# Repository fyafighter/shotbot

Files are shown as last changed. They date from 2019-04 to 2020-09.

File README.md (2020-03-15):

Shotbot is a Lacrosse goalie training system.

It runs on a raspberry pi and uses 3 docker containers: 
redis, api, and worker.

The default user on the raspberry pi is "pi" 
(naturally - however I write this down as I forgot it after not logging into the machine for 9 months after I set it up...)

1. Setup the raspberry pi.
https://www.raspberrypi.org/downloads/raspbian/

2. Install docker:
curl -fsSL get.docker.com -o get-docker.sh && sh get-docker.sh
sudo usermod -aG docker pi
newgrp docker

3. Install Docker Compose
sudo apt-get install libffi-dev libssl-dev
sudo apt-get install -y python python-pip
sudo apt-get remove python-configparser

Add vm.overcommit_memory = 1 to /etc/sysctl.conf

4. Checkout, build, and run
git clone https://github.com/fyafighter/shotbot.git
cd shotbot
docker-compose up --build

5. Download and install the app.
This can be done manually today by building and deploying from the flutter application. 
cd shotbot_app 
code .

TODO: Publish the app. 

DETAILS ON THE TARGETING SYSTEM
The Shotbot is setup on a 3x3 grid for targetting. The easiest way to get started is to start up the shotbot and the app, then center the system with the controls in the app, and then use the various shooting modes.

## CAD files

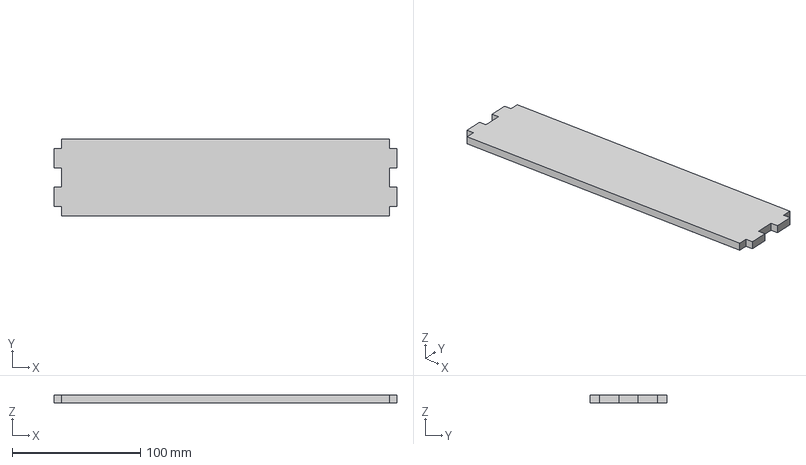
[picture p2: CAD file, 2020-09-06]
drawings/print-parts/tilt tray.step
267.0 x 60.0 x 6.00 mm

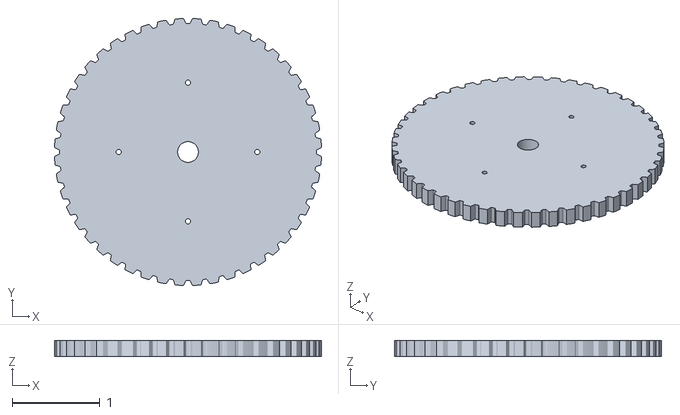
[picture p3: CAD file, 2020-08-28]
drawings/v2/tilt-XL-timing-pulley.stl
3.03 x 3.03 x 0.188

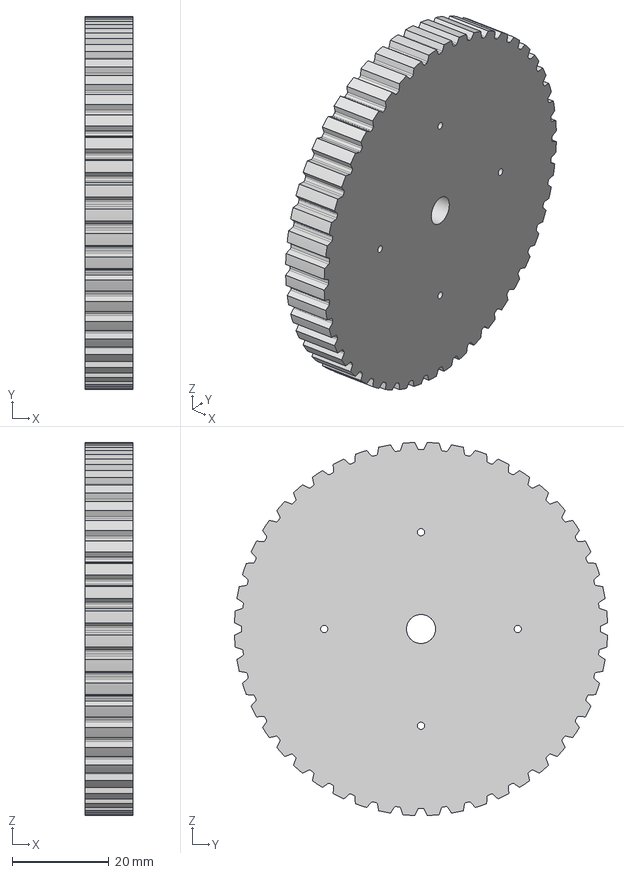
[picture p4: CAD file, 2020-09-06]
drawings/print-parts/Large gear.step
10.0 x 77.1 x 77.1 mm

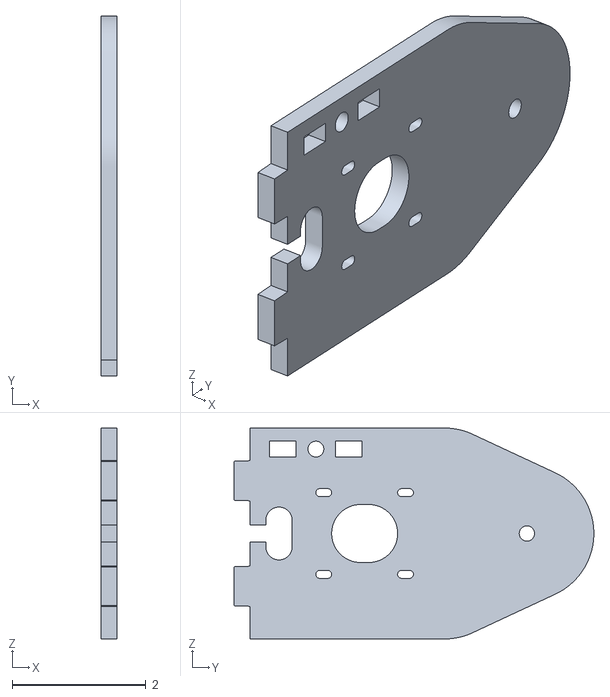
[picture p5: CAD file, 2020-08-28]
drawings/v2/pan-tray-flange.stl
0.236 x 5.37 x 3.15

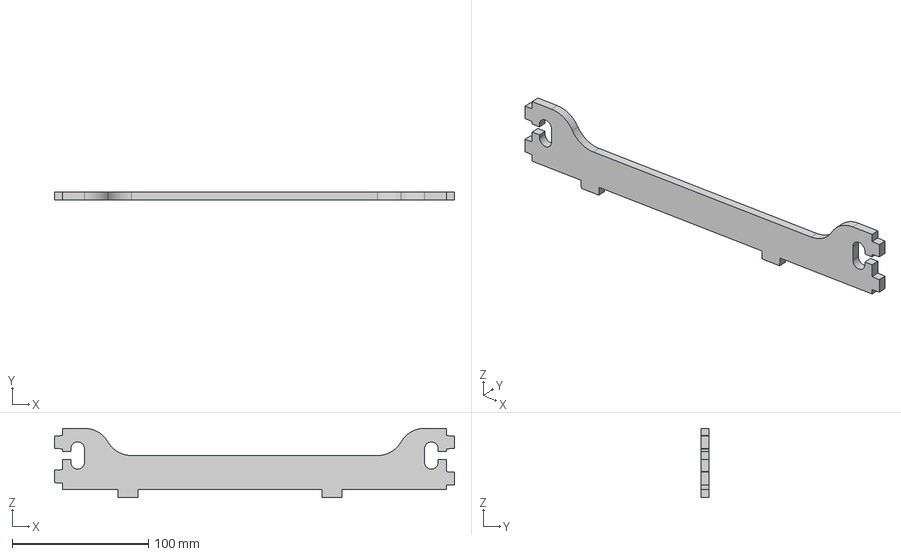
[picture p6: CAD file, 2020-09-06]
drawings/print-parts/Back support.step
294.0 x 6.00 x 51.0 mm

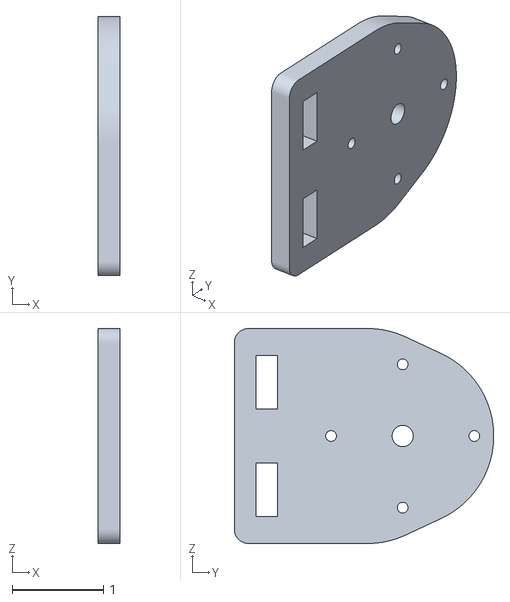
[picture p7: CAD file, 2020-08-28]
drawings/v2/tilt-tray-flange.stl
0.236 x 2.85 x 2.36

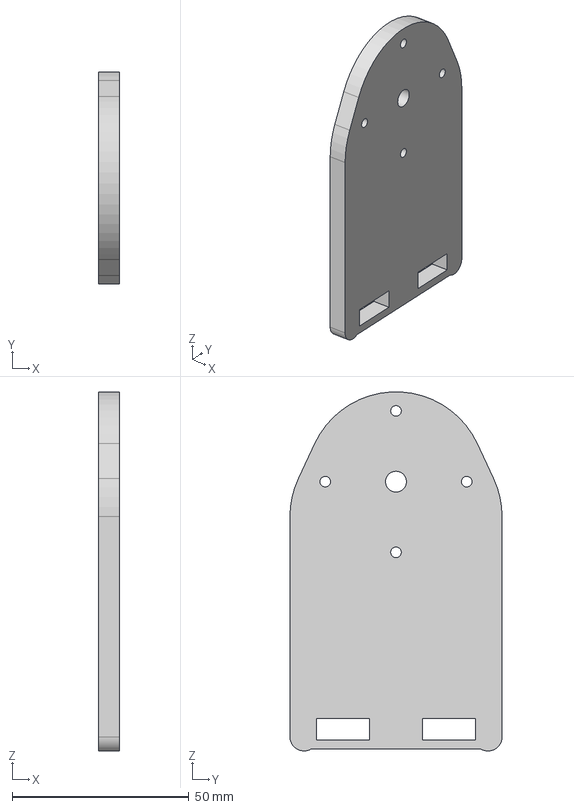
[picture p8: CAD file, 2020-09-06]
drawings/print-parts/Tilt Flange 2.step
6.00 x 60.0 x 101.5 mm

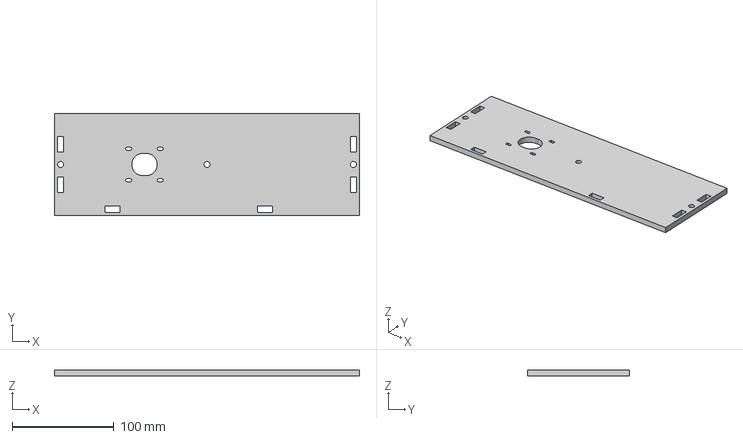
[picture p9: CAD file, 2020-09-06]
drawings/print-parts/Base Tray.step
300.0 x 100.0 x 6.00 mm

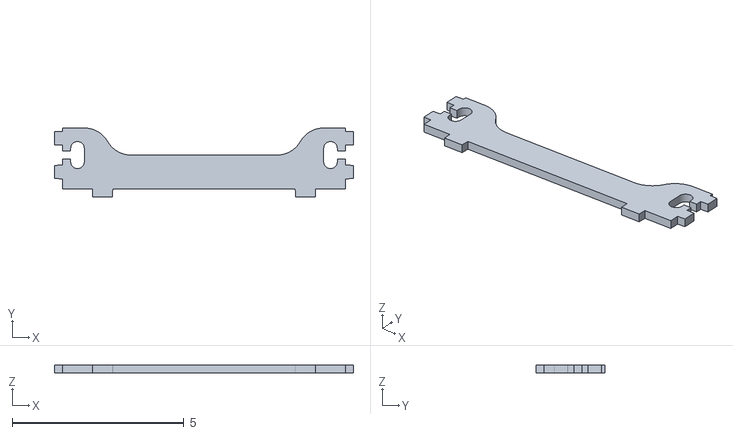
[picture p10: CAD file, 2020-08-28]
drawings/v2/pan-brace.stl
8.70 x 2.01 x 0.236

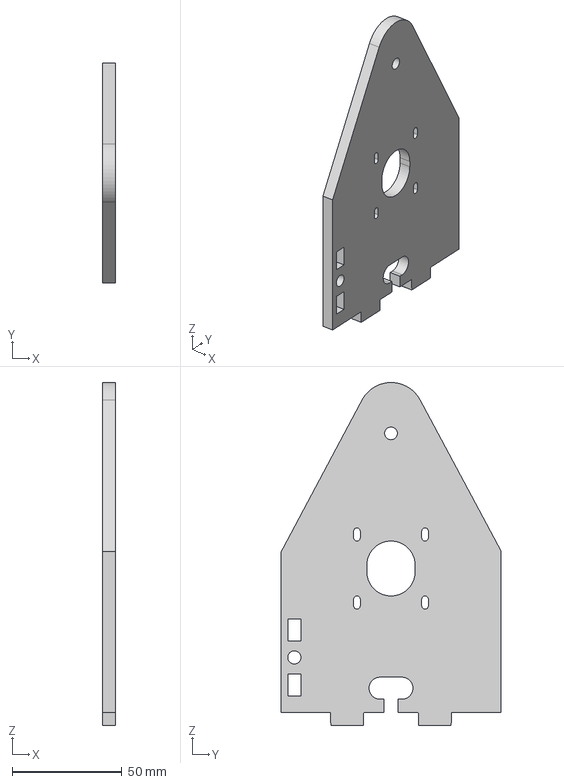
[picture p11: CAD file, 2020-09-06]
drawings/print-parts/Flange 2.step
6.00 x 100.0 x 156.2 mm

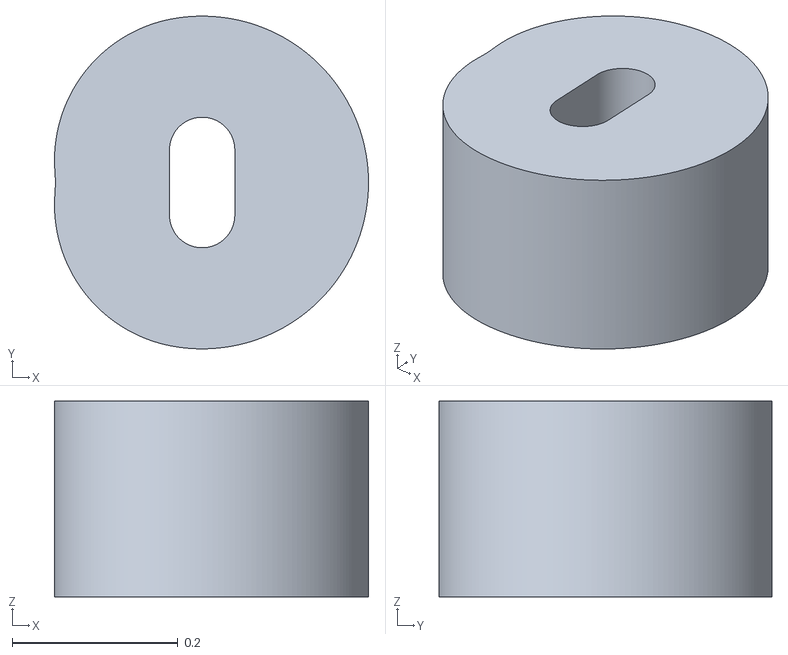
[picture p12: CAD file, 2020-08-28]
drawings/v2/drive-pulley-key.stl
0.379 x 0.402 x 0.236

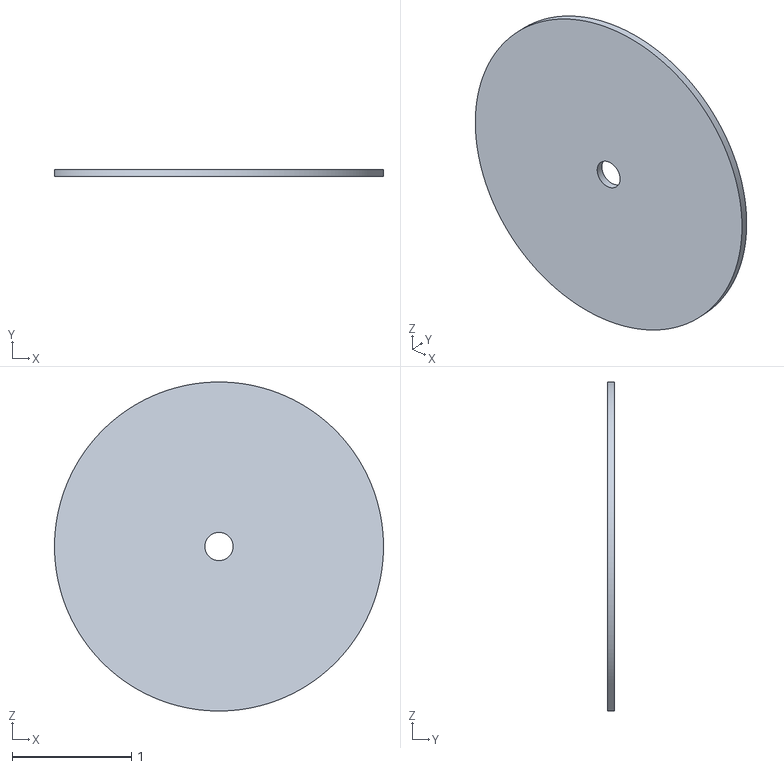
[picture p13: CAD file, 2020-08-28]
drawings/v2/pan-felt-bearing.stl
2.76 x 0.0625 x 2.76

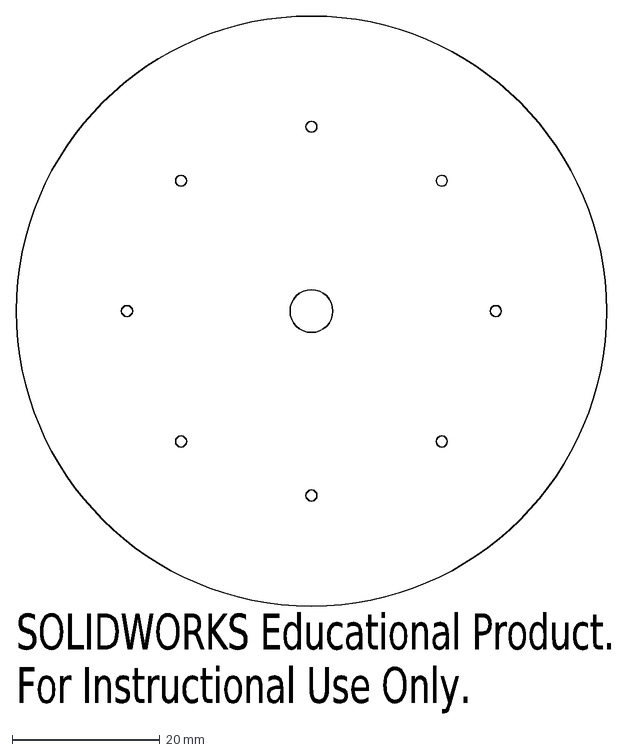
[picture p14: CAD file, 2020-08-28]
drawings/v2/pan-axis-spacer-6mm.dxf
SOLIDWORKS Educational Product.
For Instructional Use Only.

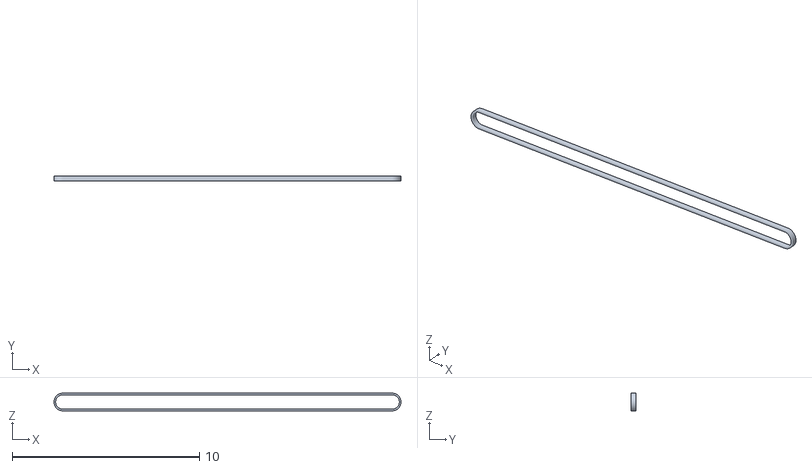
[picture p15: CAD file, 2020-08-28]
drawings/v2/XL-timing-belt.stl
18.6 x 0.25 x 0.951

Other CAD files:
drawings/v2/base1.dxf
drawings/v2/pan-axis-spacer-30mm.dxf
drawings/v2/XL-timing-pulleys.dxf
drawings/v2/pan-tray.stl
drawings/shotbot3.f3d
drawings/v2/drive-pulley-key.dxf
drawings/v2/generic-metric-washer.stl
drawings/v2/pan-XL-timing-pulley.stl
drawings/v2/pan-axis-spacer.stl
drawings/v2/pan-base.dxf
drawings/v2/pan-base.stl
drawings/v2/pan-brace.dxf
drawings/v2/pan-felt-bearing.dxf
drawings/v2/pan-tray-flange-no-motor.dxf
drawings/v2/pan-tray-flange-with-stepper.dxf
drawings/v2/pan-tray.dxf
drawings/v2/tilt-tray-flange.dxf
drawings/v2/tilt-tray.dxf
drawings/v2/tilt-tray.stl

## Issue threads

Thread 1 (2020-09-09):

3D Design receiver holes are slightly too small/unaligned. Need 0.1mm tolerance.

fyafighter, 2020-09-09:
When assembling after 3d printing the holes just barely out of alignment and require filling/dangerous force.

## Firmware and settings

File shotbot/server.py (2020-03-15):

from flask import Flask, jsonify, request
from bot import Bot
import os, json, threading, time, random

bot = Bot("main_bot")
bot_target_queue = {}
app = Flask(__name__)
app_settings = os.getenv("APP_SETTINGS")
app.config.from_object(app_settings)

@app.route('/')
def index():
  return 'Shotbot is online.'

@app.route('/command', methods=['POST'])
def command():
  command_param = request.args.get("switch")
  print(command_param)
  if (command_param in bot.get_relays()):
    bot.enqueue_manual_move(command_param)
    return ("[]")
  else:
    if (command_param=='bouncers'): grounder_shots()
    elif (command_param=='edges'): edge_shots()
    elif (command_param=='random'): random_shots()
    elif (command_param=='level') :bot.level() 
    else: bot.all_stop()
    return("Running "+ command_param)

@app.route('/target', methods=['PUT', 'GET'])
def target():
    if (request.method=='GET'):
        return jsonify(target=bot.get_target())
    elif(request.method=='PUT'):
        bot.set_target(request.json['target'][0], request.json['target'][1])
    return jsonify(target=bot.get_target())

@app.route('/stop', methods=['PUT'])
def stop():
    if(request.method=='PUT'):
        bot.all_stop()
    return jsonify(target=bot.get_target())

@app.route('/relay', methods=['PUT'])
def relay():
    if(request.method=='PUT'):
        bot.manual_move(request.json['relay'], request.json['timeout'])
    return jsonify(target=bot.get_target())

@app.route('/level', methods=['PUT'])
def level():
    if(request.method=='PUT'):
        bot.level()
    return jsonify(target=bot.get_target())

@app.route('/shotmode', methods=['PUT'])
def shotmode():
    if (request.method=='GET'):
        if request.json['target'].mode == 'edges':
            print("Running edges mode")
        elif request.json['target'].mode == 'bouncers':
            print("Running bouncers mode")
        elif request.json['target'].mode == 'random':
            print("Running random mode")

@app.route('/status', methods=['GET', 'PUT'])
def status():
    if (request.method=='GET'):
        return jsonify(status="online", relays=bot.get)

@app.route('/control', methods=['GET', 'PUT'])
def control():
    if (request.method=='PUT'):
        request.json['relay']
        return jsonify(status="online")

def grounder_shots():
    print("GROUNDERS!")
    bot.enqueue_manual_move("pitch")
    for x in range(30):
        print(str(x%3))
        target = x%3 + 1
        bot.set_target(target, 1)

def edge_shots():
    print("GRID")
    bot.enqueue_manual_move("pitch")
    for x in range(10):
        #print(str(x%3))
        target = x % 3 + 1
        #print("Moving to " + str(target) + ", 1")
        #print("Moving to " + str(target) + ", 2")
        #print("Moving to " + str(target) + ", 3")
        bot.set_target(target, 1)
        bot.set_target(target, 2)
        bot.set_target(target, 3)
        bot.set_target(1,2)
        time.sleep(0.1)

def random_shots():
    print("RANDOM!")
    bot.enqueue_manual_move("pitch")
    bot.set_target(1,1)
    for x in range(30):
        r = random.randint(1,3)
        r2 = random.randint(1,3)
        print("Moving to " + str(r) + ", " + str(r2))
        bot.set_target(r, r2)

if __name__ == '__main__':
    bot = Bot("main_bot")
    app.run(host='0.0.0.0', port=5000)

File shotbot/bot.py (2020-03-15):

from relay import Relay
import redis, time
from rq import Queue, Connection
from flask import current_app

class Bot:
    def __init__(self, name):
        self.name = name
        self.state = 0
        #The target system, is 9 squares using x,y coordinates
        # It makes more sense for the bottom right to be 1,1 rather than 0,0 
        # (as we are targeting inside the square rather than at a specific position)
        #[1,3] [2,3] [3,3]
        #[1,2] [2,2] [3,2]
        #[1,1] [2,1] [3,1]
        self.target_x = 2
        self.target_y = 2
        self.v_rate = 3
        self.h_rate = 3
        self.relays = {
            "pan": Relay("pan", 5, 90),
            "up": Relay("up", 6, 15),
            "down": Relay("down", 13, 15),
            "left": Relay("left", 16, 15),
            "right": Relay("right",19 , 15),
            "pitch": Relay("pitch", 26, 90)
        }
        print("Initializing bot and ensuring relays are off")
        for relay in self.relays:
            self.relays[relay].switchOff() 

    def get_name(self):
        return self.name
        
    def get_target(self):
        return [self.target_x, self.target_y]

    def calibrate_center(self):
        self.target_x = 2
        self.target_y = 2
        return self.get_target()

    def enqueue_manual_move(self, relay):
        with Connection(redis.from_url(current_app.config["REDIS_URL"])):
            q = Queue()
            task = q.enqueue(self.manual_move, relay)

    def manual_move(self, relay, timeout=15):
        if relay=='up':
            self.relays['down'].switchOff()
        if relay=='down':
            self.relays['up'].switchOff()
        if relay=='left':
            self.relays['right'].switchOff()
        if relay=='right':
            self.relays['left'].switchOff()
        self.relays[relay].switch()
        

    def execute_manual_move(self, relay, timeout):
        self.relays[relay].switchOn(timeout)
        time.sleep(timeout)

    def all_stop(self):
        with Connection(redis.from_url(current_app.config["REDIS_URL"])):
            q = Queue()
            print("Emptying worker queue. Current Size: " + str(q.count))
            q.empty()
        for relay in self.relays:
            self.relays[relay].switchOff()

    def execute_move(self, x_move, y_move):
        #Stop all movements before beginning a move command
        #This is done to prevent potentially sending "left and right"
        # or "up AND down" at the same time.
        self.relays['right'].switchOff()
        self.relays['left'].switchOff()
        self.relays['up'].switchOff()
        self.relays['down'].switchOff()
        self.relays['pan'].switchOff()
        total_move_seconds = 0
        if (x_move>0):
            total_move_seconds += x_move * self.h_rate
            self.relays['right'].switchOn(x_move * self.h_rate)
            print("Moving right " + str(total_move_seconds))
        elif (x_move<0):
            total_move_seconds += abs(x_move) * self.h_rate
            self.relays['left'].switchOn(abs(x_move) * self.h_rate)
            print("Moving left " + str(total_move_seconds))

        if (y_move>0):
            print("Moving up")
            if (abs(y_move) * self.h_rate>total_move_seconds): 
                total_move_seconds += abs(y_move) * self.h_rate
            self.relays['up'].switchOn(abs(y_move) * self.h_rate)
            print("Moving up " + str(total_move_seconds))
        elif (y_move<0):
            if (abs(y_move) * self.h_rate>total_move_seconds): 
                total_move_seconds += abs(y_move) * self.h_rate
            self.relays['down'].switchOn(abs(y_move) * self.h_rate)
            print("Moving down " + str(total_move_seconds))
        time.sleep(total_move_seconds)
        return total_move_seconds
    
    def set_target(self, target_x, target_y):
        x_move = 0
        y_move = 0
        if ((target_x>3) or (target_y>3) or (target_x<1) or (target_y<1)):
            raise ValueError("The target was out of bounds")
        
        if ((self.target_x != target_x) or (self.target_y != target_y)):
            #calucluate the x movement
            if (self.target_x > target_x):
                #it is smaller, move to the left
                x_move = 0-(self.target_x - target_x)
            elif (self.target_x < target_x):
                #it is larger, move to the left
                x_move = target_x - self.target_x

            if (self.target_y > target_y):
                #it is smaller, move down
                y_move = 0-(self.target_y - target_y)
            elif (self.target_y < target_y):
                #it is larger, move up
                y_move = target_y - self.target_y
            self.target_x = target_x
            self.target_y = target_y
        with Connection(redis.from_url(current_app.config["REDIS_URL"])):
            q = Queue()
            #print("Queue size: " + str(q.count))
            task = q.enqueue(self.execute_move, x_move, y_move)
        #return [x_move, y_move, task]

    def level(self):
        self.relays['up'].switchOn(30)
        time.sleep(30)
        self.relays['down'].switchOn(15)
        time.sleep(15)

    def get_relays(self):
        return self.relays

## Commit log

2019-04-13 Buttons pretty much do what I think they should. Also added http
2019-04-13 Adjust names of relays and change behavior of command buttons
2019-05-04 Update shotbot_server.py
    Upgraded to 8 relay board which required changing a bunch of stuff. Also listen on all IPs by default.
2019-05-06 Changed name from grounders to bouncers
2019-11-21 Imporove relay timeouts and add tests
2019-11-24 shorten the switch off sleep time
    [relay.py]
2019-12-08 Add center calibration and manual control.
2020-03-14 Fix relay bugs and enable GPIO
    [bot.py, relay.py, worker.py]
2020-03-15 add edges, grounders, and random
2020-03-15 Fix thread bugs
2020-03-15 Fix docker build problem and enable docker access to GPIO
    [worker.py]
2020-08-28 Adds drawings
    [XL-timing-belt.stl, XL-timing-pulleys.dxf, base1.dxf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]
2020-09-06 Clean up the drawings.
    [Back support.step, Base Tray.step, Flange 2.step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]
